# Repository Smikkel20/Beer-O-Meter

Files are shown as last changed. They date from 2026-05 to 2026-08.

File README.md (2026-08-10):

# Beer-O-Meter

A fun ATTiny-powered device that measures how quickly you can down a pint. Place a glass on the pressure plate, press the button, drink, and release — the 7-segment display shows your elapsed time in centiseconds.

## Features

- **Pressure plate / button trigger** — starts timing when pressed, stops when released.
- **TM1637 4-digit 7-segment display** — shows elapsed time live.
- **Auto-reset** — after a short cooldown, the meter is ready for the next round.
- **KiCad PCB** — custom PCB design included.

## Hardware

| Component | Description |
|---|---|
| ATTiny85 | 8-bit AVR MCU |
| TM1637 4-digit 7-segment display | Clock & data interface |
| Momentary push button / pressure plate | Input on PB2 (physical pin 7) |
| Wires / custom PCB | Connections as per KiCad design |

### Wiring

| Display / Button Pin | ATTiny85 Pin |
|---|---|
| TM1637 CLK | PB4 (physical pin 3) |
| TM1637 DIO | PB3 (physical pin 2) |
| Button (pressure plate) | PB2 (physical pin 7) |

## Usage

1. Power the PCB.
2. Place your glass on the pressure plate.
3. Pick up the glass and start drinking!
4. Put down the glass on the pressure plate when its empty.
5. The display shows your time!

## Building & Flashing

Install the ATTiny85 core (e.g. via [ATTinyCore](https://github.com/SpenceKonde/ATTinyCore)) and flash with your programmer (USBasp, AVRISP mkII, Arduino-as-ISP, etc.):

```bash
arduino-cli compile --fqbn attiny:avr:attiny85 Beer-O-Meter/
arduino-cli upload -p /dev/ttyUSB0 --fqbn attiny:avr:attiny85 Beer-O-Meter/
```

Or open `Beer-O-Meter/Beer-O-Meter.ino` in the Arduino IDE with the ATTiny85 board selected and upload.

## PCB Design

The `PCB-Design/` folder contains the KiCad project files:

- `Beer-Timer.kicad_sch` — schematic
- `Beer-Timer.kicad_pcb` — PCB layout
- `Beer-Timer.kicad_pro` — project settings
- `Beer-Timer.step` / `Beer-Timer.stl` — 3D models

Open the `.kicad_pro` file in KiCad 7+ to view or modify the design.

## License

This project is licensed under the GNU General Public License v3.0 — see [LICENSE](LICENSE).

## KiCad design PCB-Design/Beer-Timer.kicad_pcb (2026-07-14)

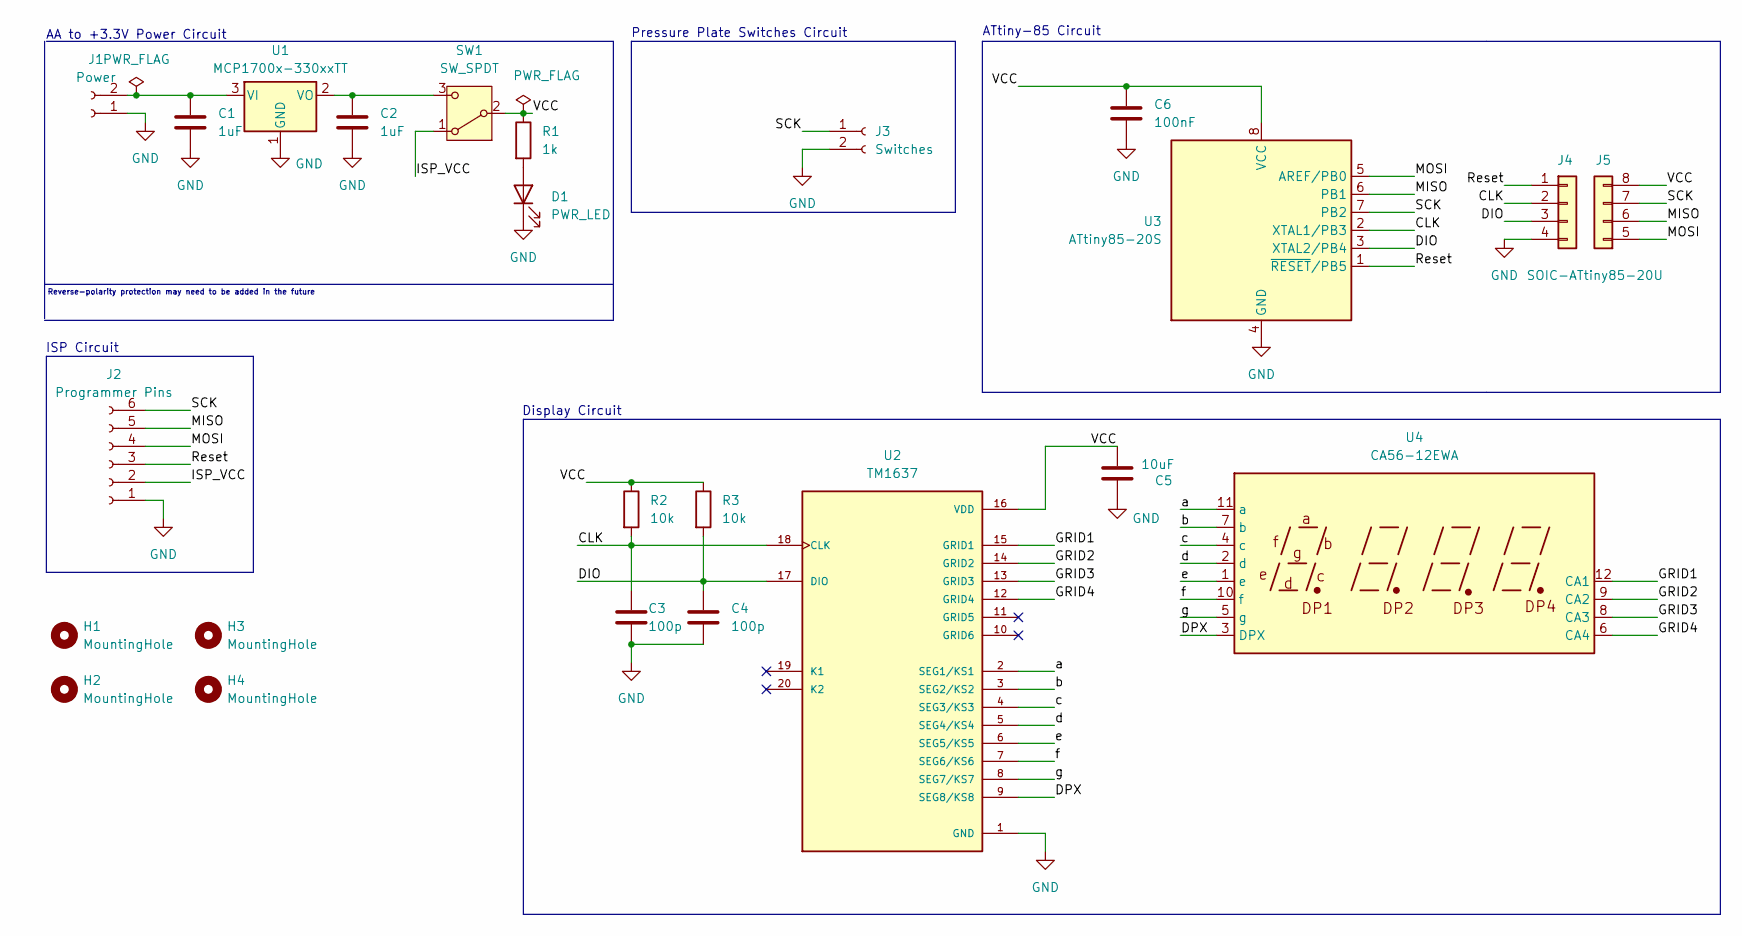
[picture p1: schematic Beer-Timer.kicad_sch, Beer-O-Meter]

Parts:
C1, C2: 1uF; C_0603_1608Metric_Pad1.08x0.95mm_HandSolder
C3, C4: 100p; C_0603_1608Metric_Pad1.08x0.95mm_HandSolder
C5: 10uF; C_0603_1608Metric_Pad1.08x0.95mm_HandSolder
C6: 100nF; C_0603_1608Metric_Pad1.08x0.95mm_HandSolder
D1: PWR_LED; LED_0603_1608Metric_Pad1.05x0.95mm_HandSolder
H1, H2, H3, H4: MountingHole; MountingHole_2.2mm_M2
J1: Power; PinHeader_1x02_P2.54mm_Vertical
J2: Programmer Pins; PinHeader_1x06_P2.54mm_Vertical
J3: Switches; PinHeader_1x02_P2.54mm_Vertical
J4: SOIC-ATtiny85-20U; PinHeader_1x04_P2.54mm_Vertical
J5: SOIC-2; PinHeader_1x04_P2.54mm_Vertical
R1: 1k; R_0603_1608Metric_Pad0.98x0.95mm_HandSolder
R2, R3: 10k; R_0603_1608Metric_Pad0.98x0.95mm_HandSolder
SW1: SW_SPDT; SW_SPDT_Shouhan_MSK12C02
U1: MCP1700x-330xxTT; SOT-23
U2: TM1637; SOP-20_7.5x12.8mm_P1.27mm; PARTREV v2.5
U3: ATtiny85-20S; SOIC-8_5.3x5.3mm_P1.27mm
U4: CA56-12EWA

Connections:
/CLK: C3.1, J4.2, R2.2, U2.18 (CLK), U3.2 (XTAL1/PB3)
/DIO: C4.1, J4.3, R3.2, U2.17 (DIO), U3.3 (XTAL2/PB4)
/DPX: U2.9 (SEG8/KS8), U4.3 (DPX)
/GRID1: U2.15 (GRID1), U4.12 (CA1)
/GRID2: U2.14 (GRID2), U4.9 (CA2)
/GRID3: U2.13 (GRID3), U4.8 (CA3)
/GRID4: U2.12 (GRID4), U4.6 (CA4)
/ISP_VCC: J2.2, SW1.1 (A)
/MISO: J2.5, J5.6, U3.6 (PB1)
/MOSI: J2.4, J5.5, U3.5 (AREF/PB0)
/Reset: J2.3, J4.1, U3.1 (~RESET/PB5)
/SCK: J2.6, J3.1, J5.7, U3.7 (PB2)
/VCC: C5.2, C6.1, J5.8, R1.1, R2.1, R3.1, SW1.2 (B), U2.16 (VDD), U3.8 (VCC)
/a: U2.2 (SEG1/KS1), U4.11 (a)
/b: U2.3 (SEG2/KS2), U4.7 (b)
/c: U2.4 (SEG3/KS3), U4.4 (c)
/d: U2.5 (SEG4/KS4), U4.2 (d)
/e: U2.6 (SEG5/KS5), U4.1 (e)
/f: U2.7 (SEG6/KS6), U4.10 (f)
/g: U2.8 (SEG7/KS7), U4.5 (g)
GND: C1.2, C2.2, C3.2, C4.2, C5.1, C6.2, D1.1 (K), J1.1, J2.1, J3.2, J4.4, U1.1 (GND), U2.1 (GND), U3.4 (GND); also elsewhere on the board
unnamed 21: D1.2 (A), R1.2; also elsewhere on the board
unnamed: C1.1, J1.2, U1.3 (VI)
unnamed: C2.1, SW1.3 (C), U1.2 (VO)

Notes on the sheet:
ISP Circuit
AA to +3.3V Power Circuit
Display Circuit
ATtiny-85 Circuit
Pressure Plate Switches Circuit
Reverse-polarity protection may need to be added in the future

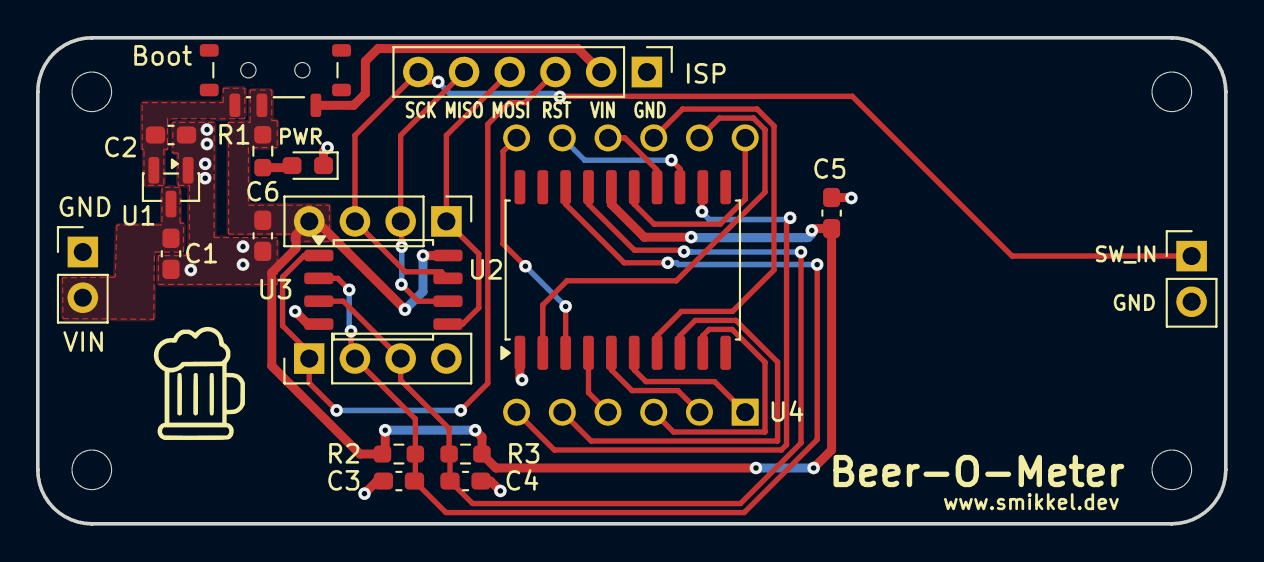
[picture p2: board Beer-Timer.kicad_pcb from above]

Board: 2 copper layers, 66.0 x 27.0 mm, 24 parts (1 on the bottom side), 24 nets.

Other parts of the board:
PWR: PWR_LED; LED_0603_1608Metric_Pad1.05x0.95mm_HandSolder

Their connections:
GND: PWR.1 (K); also elsewhere on the board
unnamed 21: PWR.2 (A); also elsewhere on the board

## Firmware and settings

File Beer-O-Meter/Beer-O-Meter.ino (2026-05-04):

#include <Arduino.h>
#include <TM1637Display.h>

// Module connection pins (Digital Pins)
#define CLK 4
#define DIO 3


#define BUTTON 2

TM1637Display display(CLK, DIO);
int HasTimed = 0;

int delaytime = 2000;
bool displayOn = true;
int delaystart = 0;

void setup() {
  // set up the display
  display.setBrightness(0, true);
  display.showNumberDecEx(0, (0x80 >> 1), true);   // Display initial value "0" on the screen

  // set up the pressure plate
  pinMode(BUTTON, INPUT_PULLUP);
}

void loop() {
  int Switch = digitalRead(BUTTON);   // Read current state of the pressure plate

  if (Switch == 1 && millis() - delaystart > delaytime) {
    HasTimed = 0;
  }


  while(Switch == 0 && HasTimed == 0){

    display.showNumberDecEx(0, (0x80 >> 1), true);   // Show "0" on display while waiting
    delay(100);

    Switch = digitalRead(BUTTON);

    if (Switch == 1) {  // Button has been released - start timing process
      unsigned long start = millis();

      while (Switch == 1) {
        Switch = digitalRead(BUTTON);
        unsigned long time = (millis() - start)/10;
        display.showNumberDecEx(time, (0x80 >> 1), true);   // Display current elapsed time
      }

      // Button has been released - stop the timer
      unsigned long time = (millis() - start)/10;

      HasTimed = 1;
      display.showNumberDecEx(time, (0x80 >> 1), true);   // Show the final measured time on display

      delaystart = millis();
    }
  }
}

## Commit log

2026-05-04 Updated for the ATtiny85
    Code for the microcontroller has been reworked for the new ATtiny85 instead of the Arduino for less power usage.
    [Beer-O-Meter.ino]
2026-05-04 Create .gitignore
    gitignore for KiCad
2026-05-04 Added the PCB Design
    [Beer-Timer.kicad_pcb, Beer-Timer.kicad_sch]
2026-07-14 Final PCB changes
    [Beer-Timer.kicad_pcb, Beer-Timer.kicad_sch]
